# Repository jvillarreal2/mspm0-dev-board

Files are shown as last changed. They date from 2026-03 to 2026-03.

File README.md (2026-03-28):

# MSPM0G3507 Development Board

custom 2-layer development board designed in KiCad.

## Features
- USB-C input with ESD protection (USBLC6-2SC6)
- 3.3V LDO power regulation (SPX3819)
- MSPM0G3507 ARM Cortex-M0+ MCU at 80MHz
- 8MHz external crystal oscillator
- CH340E USB-UART converter for PC communication
- LIS2DH accelerometer over I2C
- SWD debug interface (Tag-Connect)
- Ground plane on B.Cu

## Tools
- KiCad 10.0
- JLCPCB for fabrication

## Status
REV A — Design complete, awaiting fabrication.
Not final — known improvements for REV B:
- Shorten HFXIN crystal trace (currently 14mm, target <5mm)
- Review CC1/CC2 pull-down resistor values for USB-PD compatibility

### 3D View
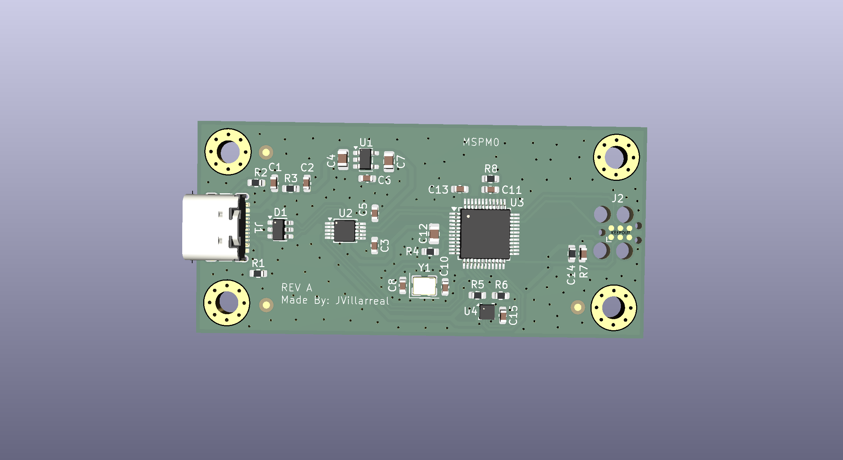
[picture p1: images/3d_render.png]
3D Render


### PCB Layout
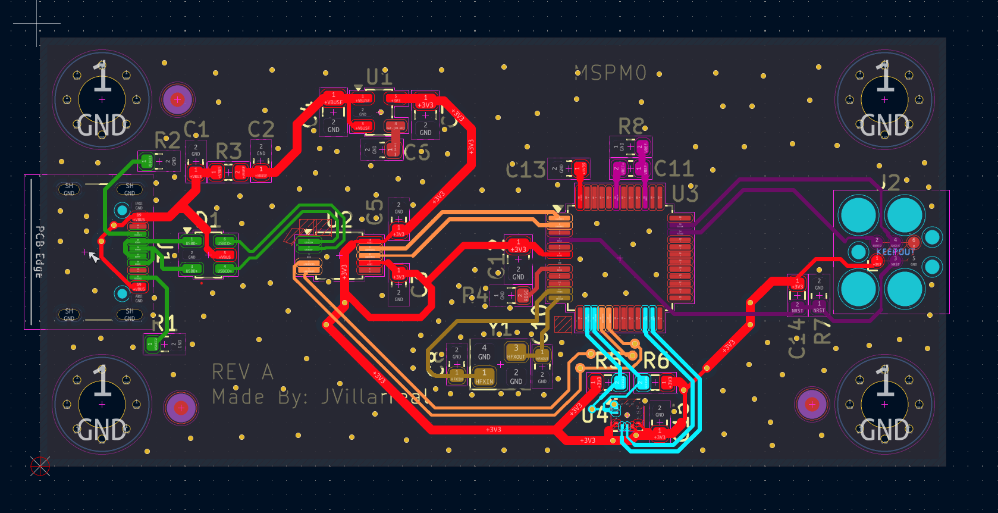
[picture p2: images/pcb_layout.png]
PCB Layout


### Top Layer
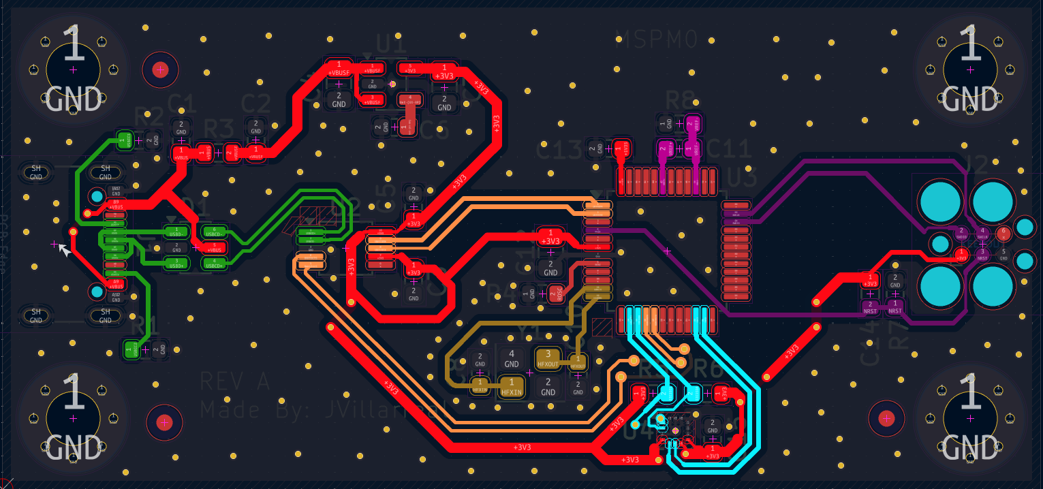
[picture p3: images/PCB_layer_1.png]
Top Layer


### Bottom Layer
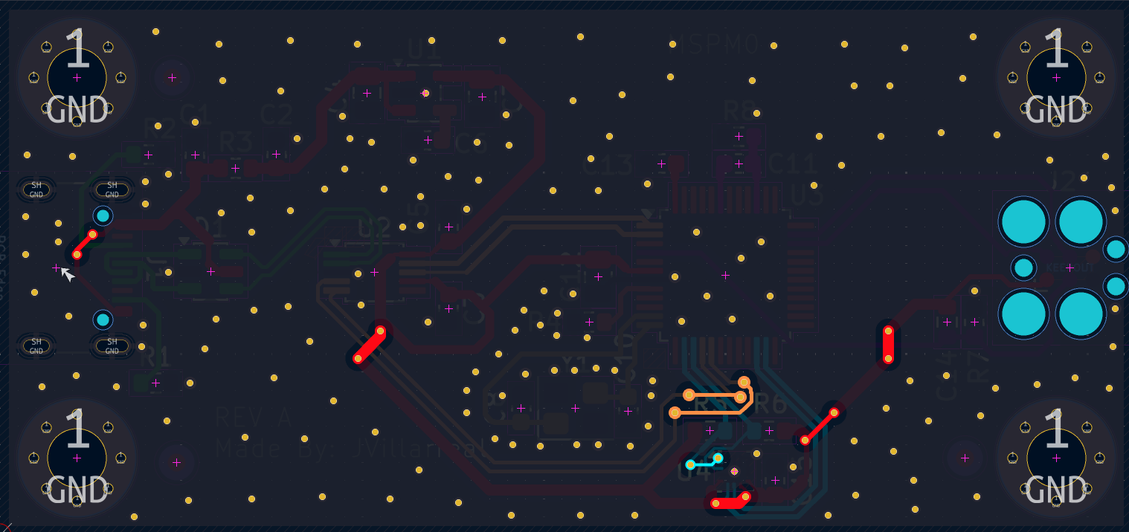
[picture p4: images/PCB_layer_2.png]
Bottom Layer


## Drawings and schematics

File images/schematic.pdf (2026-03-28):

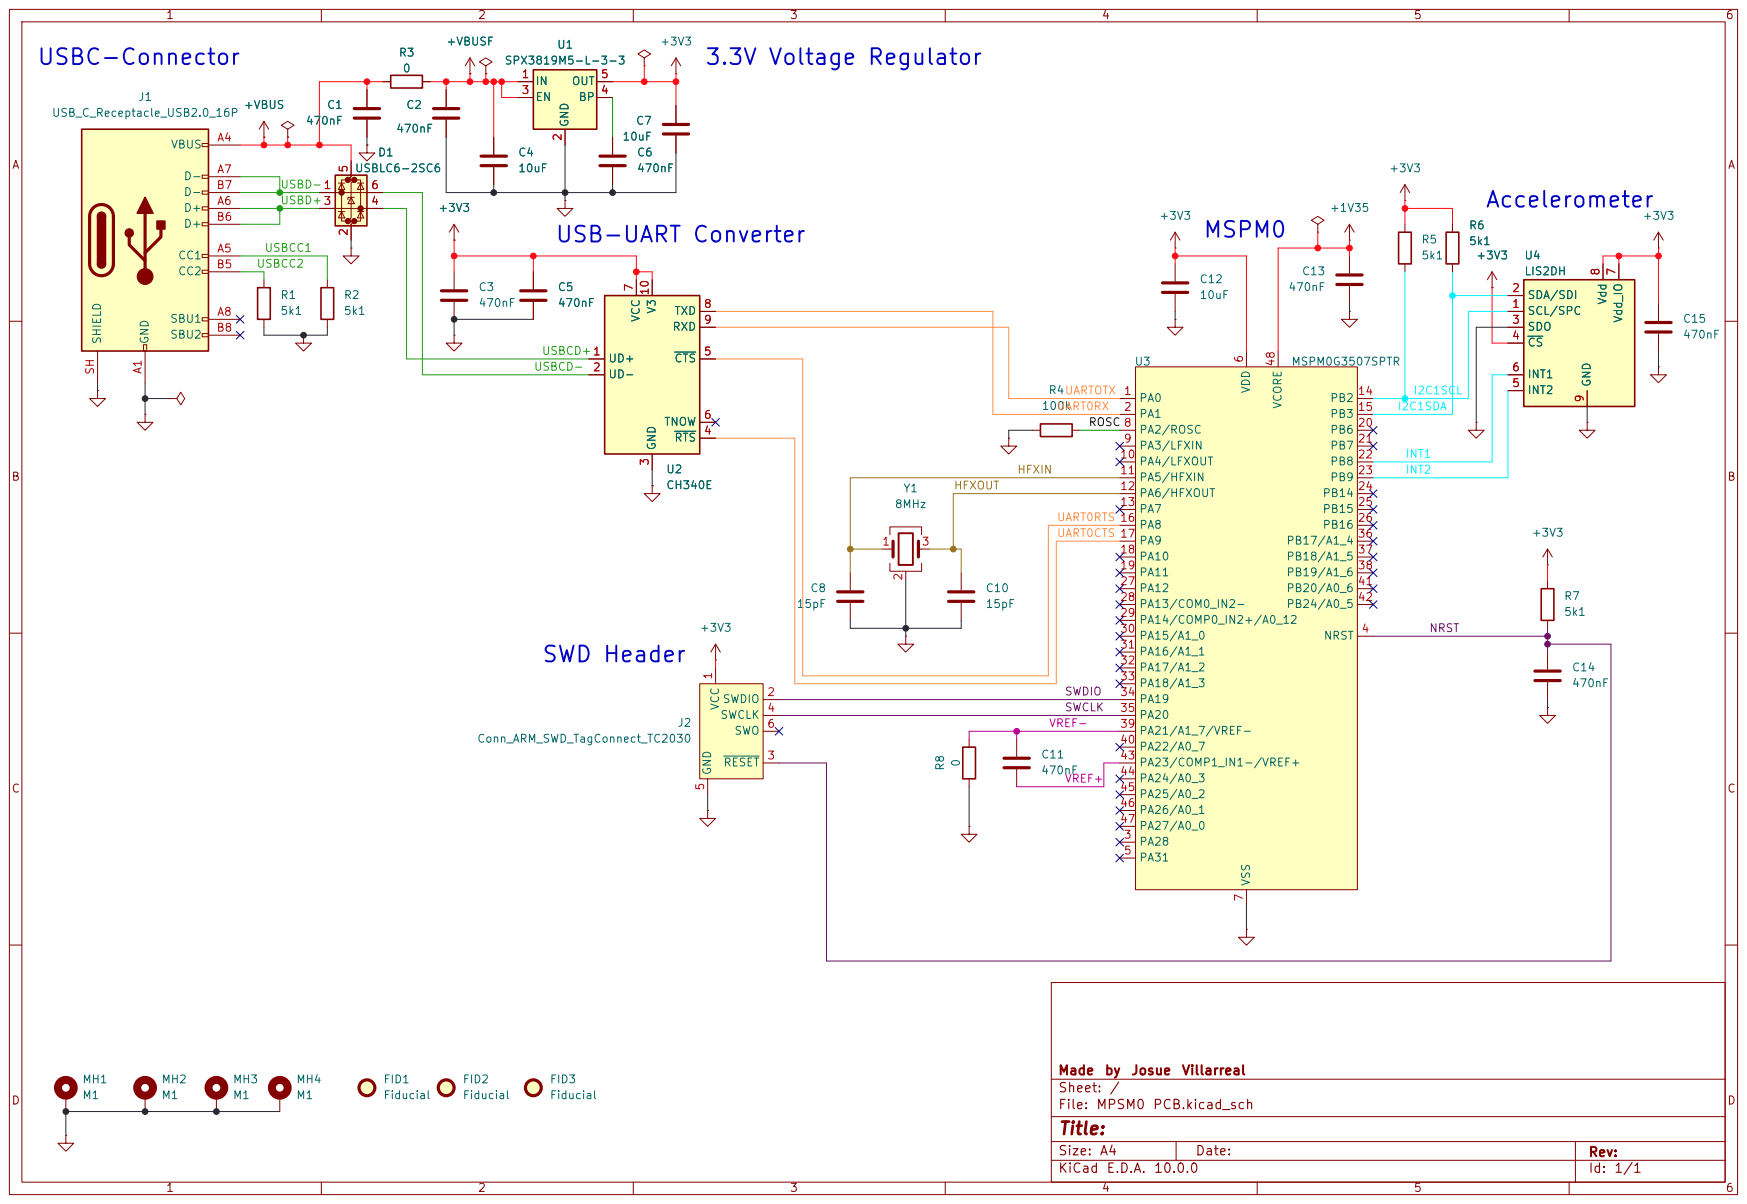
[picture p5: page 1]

SWCLK UART0RX UART0RTS UARTOTX ROSC USBD-
USBD+

I2C1SCL VREF+ USB-UART Converter

7 PA2/ROSC 8 PA3/LFXIN 9 PA4/LFXOUT 10 PA5/HFXIN 11 PA6/HFXOUT 12 PA7 13 PB2 14 PB3 15 PA8 16 PA9 17 PA10 18 PA11 19 PB6 20 PB7 21 PB8 22 PB9 23 PB14 24 PB15 25 PB16 26 PA12 27 PA13/COM0_IN2- 28 PA14/COMP0_IN2+/A0_12 29 PA15/A1_0 30 PA16/A1_1 31 PA17/A1_2 32 PA18/A1_3 33 PA19 34 PA20 35 PB17/A1_4 36 PB18/A1_5 37 PB19/A1_6 38 PA21/A1_7/VREF- 39 PA22/A0_7 40 PB20/A0_6 41 PB24/A0_5 42 PA23/COMP1_IN1-/VREF+ 43 PA24/A0_3 44 PA25/A0_2 45 PA26/A0_1 46 PA27/A0_0 47 VCORE U3 48MSPM0G3507SPTR

Made by Josue Villarreal
Sheet: /
File: MPSM0 PCB.kicad_sch
Title:

Size: A4 | Rev:
KiCad E.D.A. 10.0.0 | Id: 1/1

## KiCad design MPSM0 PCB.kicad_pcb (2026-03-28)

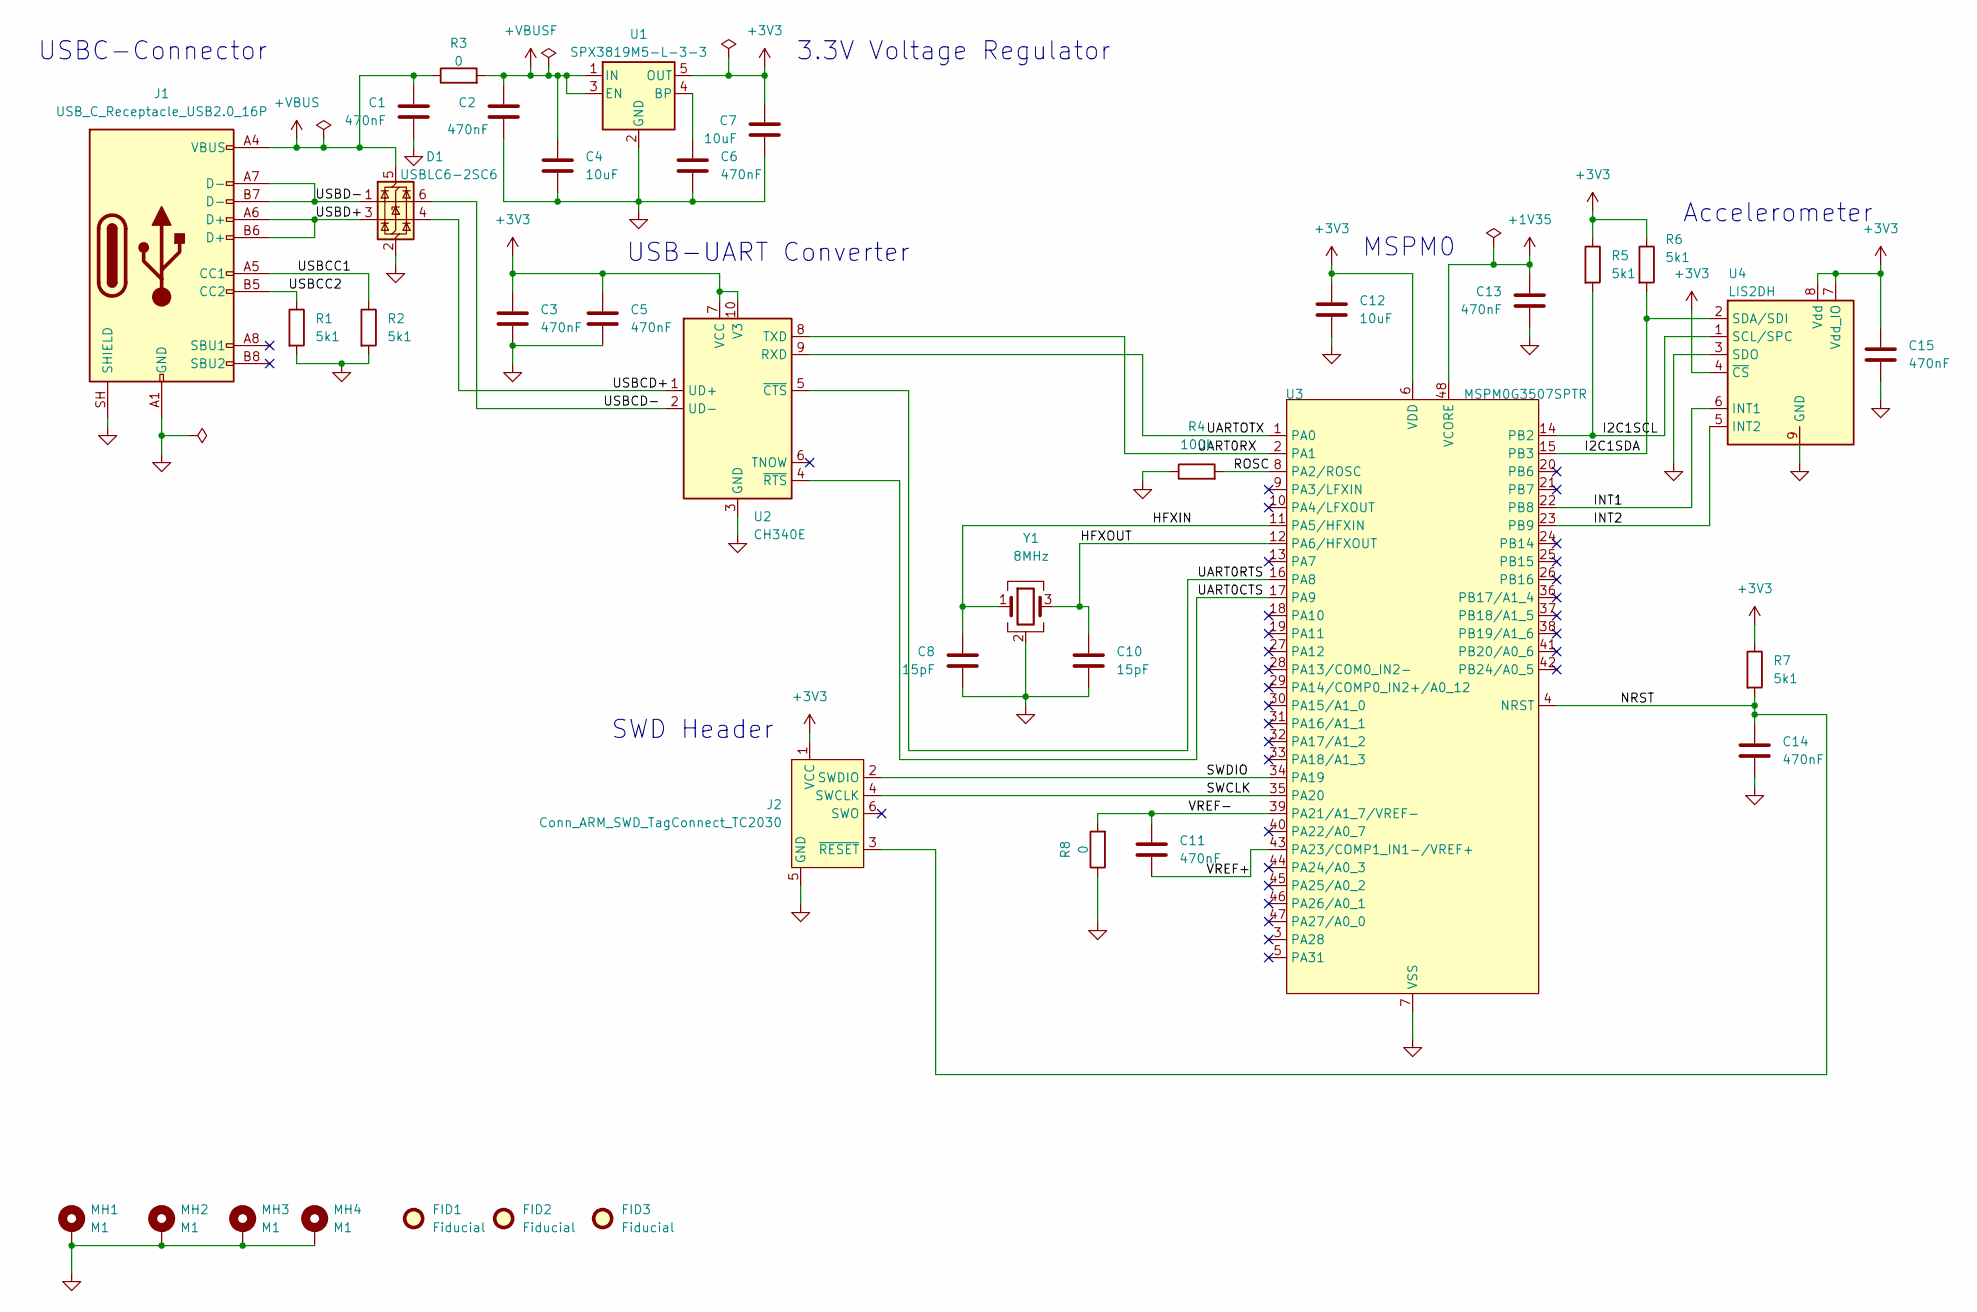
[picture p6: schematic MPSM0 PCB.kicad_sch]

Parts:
C1, C2, C3, C5, C6, C11, C13, C14, C15: 470nF; C_0603_1608Metric
C4, C7, C12: 10uF; C_0805_2012Metric
C8, C10: 15pF; C_0603_1608Metric
D1: USBLC6-2SC6; SOT-23-6
FID1, FID2, FID3: Fiducial; Fiducial_1mm_Mask2mm
J1: USB_C_Receptacle_USB2.0_16P; USB_C_Receptacle_GCT_USB4105-xx-A_16P_TopMnt_Horizontal
J2: Conn_ARM_SWD_TagConnect_TC2030; Tag-Connect_TC2030-IDC-FP_2x03_P1.27mm_Vertical
MH1, MH2, MH3, MH4: M1; MountingHole_3.2mm_M3_Pad_Via
R1, R2, R5, R6, R7: 5k1; R_0603_1608Metric
R3, R8: 0; R_0603_1608Metric
R4: 100k; R_0603_1608Metric
U1: SPX3819M5-L-3-3; SOT-23-5
U2: CH340E; MSOP-10_3x3mm_P0.5mm
U3: MSPM0G3507SPTR; LQFP-48_7x7mm_P0.5mm
U4: LIS2DH; LGA-14_2x2mm_P0.35mm_LayoutBorder3x4y
Y1: 8MHz; Crystal_SMD_3225-4Pin_3.2x2.5mm

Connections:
+1V35: C13.1, U3.48 (VCORE)
+3V3: C3.1, C5.1, C7.1, C12.1, C15.1, J2.1 (VCC), R5.1, R6.1, R7.1, U1.5 (OUT), U2.7 (VCC), U2.10 (V3), U3.6 (VDD), U4.4 (~CS), U4.7 (Vdd_IO), U4.8 (Vdd)
+VBUS: C1.1, D1.5 (VBUS), J1.A4 (VBUS), J1.A9 (VBUS), J1.B4 (VBUS), J1.B9 (VBUS), R3.1
+VBUSF: C2.1, C4.1, R3.2, U1.1 (IN), U1.3 (EN)
/HFXIN: C8.1, U3.11 (PA5/HFXIN), Y1.1
/HFXOUT: C10.1, U3.12 (PA6/HFXOUT), Y1.3
/I2C1SCL: R5.2, U3.14 (PB2), U4.1 (SCL/SPC)
/I2C1SDA: R6.2, U3.15 (PB3), U4.2 (SDA/SDI)
/INT1: U3.22 (PB8), U4.6 (INT1)
/INT2: U3.23 (PB9), U4.5 (INT2)
/NRST: C14.1, J2.3 (~RESET), R7.2, U3.4 (NRST)
/ROSC: R4.2, U3.8 (PA2/ROSC)
/SWCLK: J2.4 (SWCLK), U3.35 (PA20)
/SWDIO: J2.2 (SWDIO), U3.34 (PA19)
/UART0CTS: U2.4 (~RTS), U3.17 (PA9)
/UART0RTS: U2.5 (~CTS), U3.16 (PA8)
/UART0RX: U2.8 (TXD), U3.2 (PA1)
/UARTOTX: U2.9 (RXD), U3.1 (PA0)
/USBCC1: J1.A5 (CC1), R2.1
/USBCC2: J1.B5 (CC2), R1.1
/USBCD+: D1.4 (I/O2), U2.1 (UD+)
/USBCD-: D1.6 (I/O1), U2.2 (UD-)
/USBD+: D1.3 (I/O2), J1.A6 (D+), J1.B6 (D+)
/USBD-: D1.1 (I/O1), J1.A7 (D-), J1.B7 (D-)
/VREF+: C11.2, U3.43 (PA23/COMP1_IN1-/VREF+)
/VREF-: C11.1, R8.2, U3.39 (PA21/A1_7/VREF-)
GND: C1.2, C2.2, C3.2, C4.2, C5.2, C6.2, C7.2, C8.2, C10.2, C12.2, C13.2, C14.2, C15.2, D1.2 (GND), J1.A1 (GND), J1.A12 (GND), J1.B1 (GND), J1.B12 (GND), J1.SH (SHIELD), J2.5 (GND), MH1.1 (1_1), MH2.1 (1_1), MH3.1 (1_1), MH4.1 (1_1), R1.2, R2.2, R4.1, R8.1, U1.2 (GND), U2.3 (GND), U3.7 (VSS), U4.3 (SDO), U4.9 (GND), U4.10 (GND), U4.11 (GND), U4.12 (GND), U4.13 (GND), U4.14 (GND), Y1.2 (G), Y1.4 (G)
unnamed: C6.1, U1.4 (BP)

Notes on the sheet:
SWD Header
3.3V Voltage Regulator
USB-UART Converter
USBC-Connector
MSPM0
Accelerometer

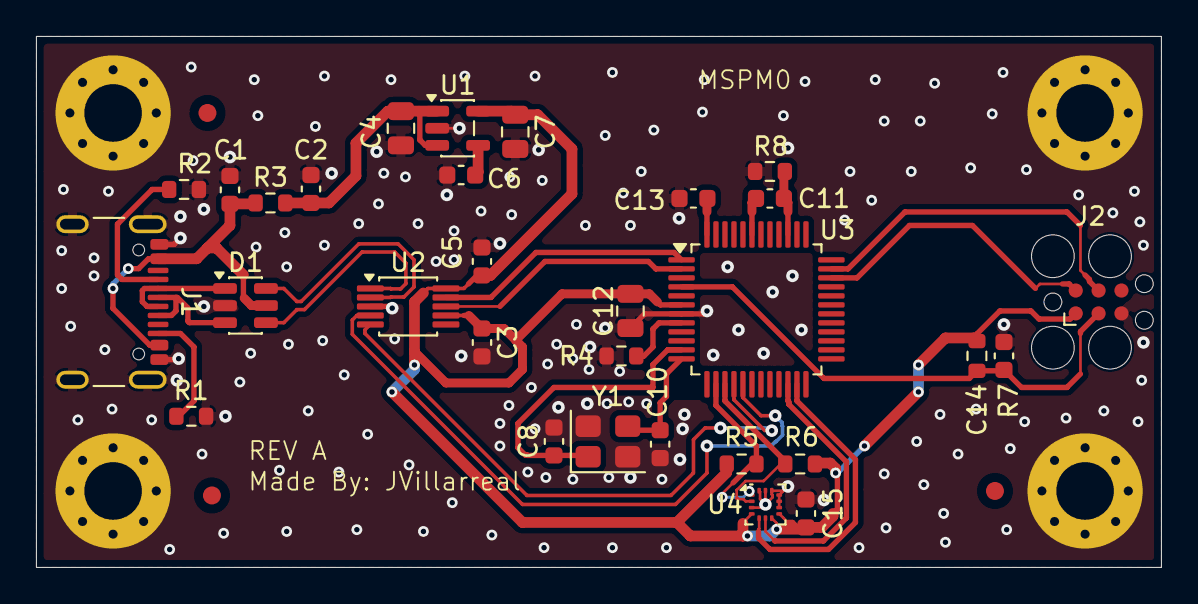
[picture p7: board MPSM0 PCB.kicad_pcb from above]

Board: 2 copper layers, 62.5 x 29.5 mm, 37 parts (0 on the bottom side), 28 nets.

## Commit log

2026-03-28 Rename MPSM0 PCB.pdf to MPSM0_PCB.pdf
2026-03-28 Rename MPSM0 PCB.png to 3d_render.png
2026-03-28 Rename PCB layer_1.png to PCB_layer_1.png
2026-03-28 Rename PCB layer_2.png to PCB_layer_2.png
2026-03-28 Rename pcb layout.png to pcb_layout.png
